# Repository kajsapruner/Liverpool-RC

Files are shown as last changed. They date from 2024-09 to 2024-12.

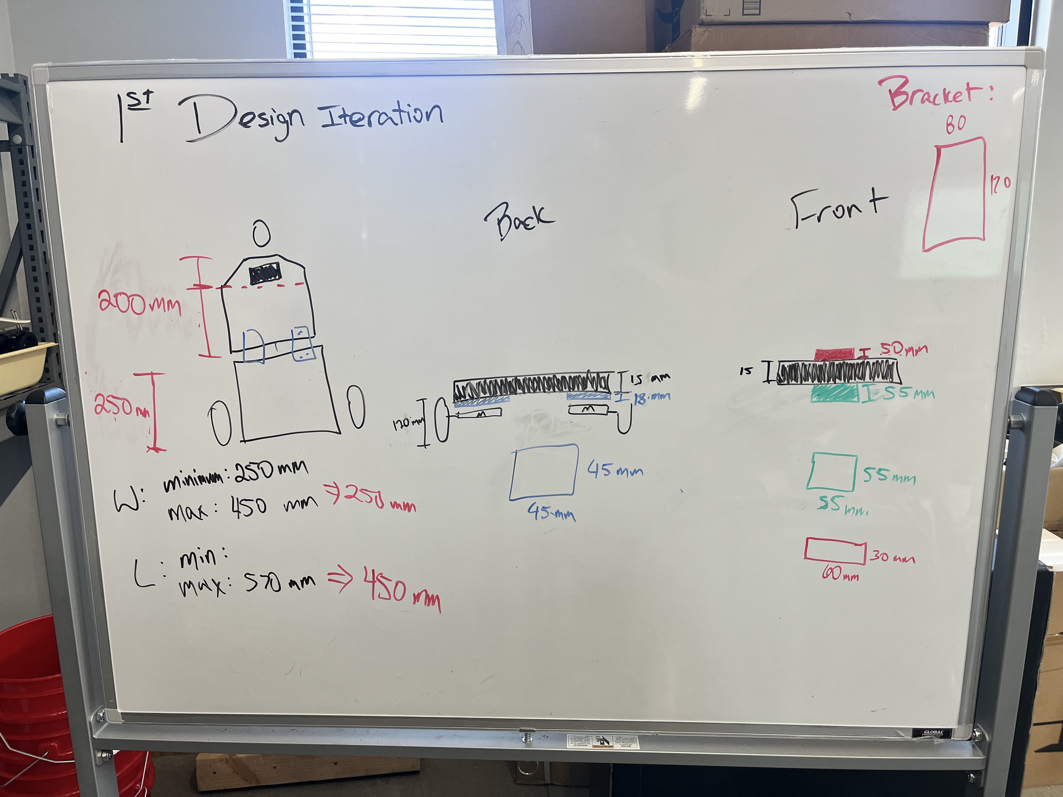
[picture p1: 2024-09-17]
Design Interations/IMG_3937.jpg

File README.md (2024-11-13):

# Liverpool-RC

The Liverpool-RC project is an advanced autonomous driving robot designed to operate using a Raspberry Pi 5 running Raspberry Pi OS. This platform aims to leverage AI and machine learning techniques to enable the robot to navigate and make decisions in real-time, evolving into a fully autonomous self-driving system. Through continuous training and refinement, the robot will learn to recognize and respond to its environment, ultimately developing the capability to drive independently with minimal human intervention. 

## Hardware
Raspberry Pi 5
Raspberry Pi Pico
Voltage Divider
Motor Driver
Switch
Battery
70:1 Motors
Wheels

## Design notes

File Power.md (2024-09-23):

## Power Supplies

### Jetson
To power the Jetson we need a power consumption ranging between 7.5 to 15 W depending on the workload. The input will usually be a 5V-4A (20W) power supply.

### Motors
12V or 24V LiPo (Lithium Polymer Batteries) with high mAh capacity to ensure longer operational time. 

A good idea will be to seperate the Jetson and other electronic components (Like Raspberry Pi Pico) from the motors. We do not want voltage drops and electrical noise. Do this with seperate power supply or voltage regulator.

### Conclusion on what we need:
- 4S 14.8V Lipo Battery (5000mAh)
- seperate 5V 4A regulator from LiPo to Supply Jetson.
- Power motors directly from 12 or 24V battery, or through motor controllers that regulate voltage.

## Switches
For safety reasons and convenience we will have switches between power supplies and components. With these switches we can control what parts of the robot that are powered at a specific time.
After research best option will probably be toggle or rocker switches with appropriate current and voltage (12/24V DC for motors)

One switch will control the entire robot, cutting off power to all the components. Another one will independently control the Jetson, one will disconnect the motor system so that we can power the robot but not activate the motors. The last one will power the Raspberry Pi Pico independently (optional but could be convienient for debugging).

### Conclusion on what we need:
- Master Switch: Use a heavy-duty toggle or rocker switch rated for the voltage of your battery (e.g., 12V or 24V) and at least 10A current.
- Jetson Switch: A smaller switch rated for 5V DC and 5A.
- Motor Switch: A high-current-rated switch, such as a 12V 20A rocker switch.
- Raspberry Pi Pico Switch: Similar to the Jetson, you can use a smaller switch rated for 5V DC and 2-5A.

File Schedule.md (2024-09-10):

### Project Timeline: September to December
## Week 1: September 4 - September 10
- Goal: Initial Setup and Component Integration
- Tasks:
  - Set up the development environment on the Jetson Orin Nano.
  - Install ROS 2 Humble on the Jetson.
  - Verify communication between the Jetson Orin Nano and Raspberry Pi Pico via UART.
  - Test basic motor control using Raspberry Pi Pico.
  - Integrate the RPLIDAR with the Jetson and verify data collection using rplidar_ros.
## Week 2: September 11 - September 17
- Goal: Establish Basic Robot Motion and Data Handling
- Tasks:
  - Develop a custom ROS node on the Jetson for motor command transmission to the Raspberry Pi Pico.
  - Implement basic forward, backward, and turning commands using ROS on the Jetson.
  - Start basic data logging from encoders and RPLIDAR.
  - Review and refine the motor control loop on the Raspberry Pi Pico to ensure accurate execution of commands.
## Week 3: September 18 - September 24
- Goal: SLAM and Initial Mapping
- Tasks:
  - Set up and test the slam_toolbox or cartographer_ros for SLAM using the RPLIDAR.
  - Begin generating initial maps of the test environment.\
  - Start basic localization tasks using robot_localization with encoder data.
  - Evaluate the accuracy of the generated maps and localization.
## Week 4: September 25 - October 1
- Goal: Autonomous Navigation Basics
- Tasks:
  - Set up the navigation2 stack and integrate it with the SLAM system.
  - Implement basic waypoint following using navigation2.
  - Test obstacle avoidance using the RPLIDAR data.
  - Fine-tune the communication between ROS nodes for smooth operation.
## Week 5: October 2 - October 8
- Goal: Sensor Fusion and Odometry Improvement
- Tasks:
  - Implement sensor fusion using robot_localization to improve odometry.
  - Integrate any additional sensors (IMU if available) for enhanced localization accuracy.
  - Continue testing and refining navigation in more complex environments.
  - Analyze and improve the performance of the SLAM and navigation algorithms.
## Week 6: October 9 - October 15
- Goal: Advanced Navigation and Path Planning
- Tasks:
  - Implement advanced path planning strategies with navigation2.
  - Begin testing autonomous navigation through more dynamic environments.
  - Start integrating additional features like object detection if using cameras.
  - Document any challenges and start a troubleshooting log.
## Week 7: October 16 - October 22
- Goal: Integration of Object Detection and AI Features (Optional)
- Tasks:
  - Integrate OpenCV and TensorFlow/PyTorch for any AI-based tasks, if applicable.
  - Start working on object detection, lane following, or other vision-based tasks.
  - Continue refining the SLAM and navigation systems.
  - Perform integration testing with all components working together.
## Week 8: October 23 - October 29
- Goal: Simulation and Testing
- Tasks:
  - Set up and test the robot in Gazebo or a similar simulation environment.
  - Run various scenarios to validate autonomous behavior.
  - Start stress-testing the system with more complex navigation tasks.
  - Collect performance data and make necessary adjustments.
## Week 9: October 30 - November 5
- Goal: Field Testing and Real-World Application
- Tasks:
  - Begin real-world field testing in the intended operational environment.
  - Collect data on performance in different conditions and adjust algorithms as needed.
  - Document any observed issues and start the debugging process.
  - Conduct team reviews to ensure all functionalities are working as expected.
## Week 10: November 6 - November 12
- Goal: Debugging and Optimization
- Tasks:
  - Focus on resolving any outstanding bugs or performance issues.
  - Optimize the communication between the Jetson and Raspberry Pi Pico.
  - Ensure smooth operation of the SLAM, navigation, and motor control systems.
  - Start finalizing the documentation for the project.
## Week 11: November 13 - November 19
- Goal: Final Integration and Testing
- Tasks:
  - Perform full system integration tests.
  - Test the robot's autonomy in various real-world scenarios.
  - Prepare a demo showcasing the robot's capabilities.
  - Gather feedback from team members and stakeholders for any last-minute adjustments.
## Week 12: November 20 - November 26
- Goal: Final Adjustments and Polishing
- Tasks:
  - Make any final tweaks and improvements based on feedback.
  - Ensure all documentation is up to date and comprehensive.
  - Prepare the robot for the final demonstration.
  - Conduct a final review meeting to confirm readiness.
## Week 13: November 27 - December 3
- Goal: Final Presentation and Project Submission
- Tasks:
  - Conduct the final demonstration of the autonomous robot.
  - Submit all project documentation, code, and reports.
  - Celebrate the successful completion of the project!

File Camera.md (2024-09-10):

# Packages that are essential for the Logitech camera

## Jetson Multimedia API
Often already preinstalled on most Jetson boards.

## v4l2 (Video for Linux 2)
Since the logitech camera uses a normal USB port we will need v4l2 so that the Jetson can interface this.
- Package: v4l-utils
- Command: sudo apt-get install v4l-utils
- You can use v4l2-ctl to check if the Jetson detects the camera.

## OpenCV
Will allow us to process the camera´s video feed, can capture frames from USB cameras (like Logitech) and has a number of computer 
vision libraries to help with object detection and image filtering for example.
- Commands:
-     sudo apt-get update
-     sudo apt-get install python3-opencv

## GStreamer
Often used on Jetson boards to support the use of hardware-accelerated video encoding/decoding and is compitable
with OpenCV (might not be neccesary but good to have?????)
- Commands:
-     sudo apt-get install gstreamer1.0-tools
-     sudo apt-get install gstreamer1.0-plugins-base gstreamer1.0-plugins-good

## PyTorch or TensorFlow
This is optional. If we are incorporating deep learning-based navigations (object recognition, reinforcement learning) we
will want either of these installed. Jetson has support for both libraries optimized for its GPUs.
- Follow these instructions to download this: https://docs.nvidia.com/deeplearning/frameworks/install-pytorch-jetson-platform/index.html

# Other resources that I found that can be helpful when downloading packages and installing camera:
## NVIDIA Jetson Forum
Good for troubleshooting and tips
https://forums.developer.nvidia.com/

## NVIDIA Developer Documentation
Includes guides on multimedia, computer vision, and deep learning.
https://docs.nvidia.com/

## GitHub
We can look for Jetson and camera-related repositories here, and take help from other similar projects.

## OpenCV Tutorials
Find tutorials here and documentation specific to video input from cameras. Could help in the installation.
https://opencv.org/

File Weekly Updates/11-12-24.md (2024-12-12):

## Ethan Durham
### This Week: 
- Did some troubleshooting on Virgil, by rewiring the motor driver.
- Assisted in enocoder program for track in the CCCS.
- Began brainstorming ideas for future model training development.
### Future Goals:
- Decide on model we want to use to train Virgil.
- Start collecting data to begin model training.
- Begin a new base design with a main goal of locking rear motors into place, so there is no wiggle when driving.

## Reagan Graff
### This Week: 
- Rewired virgil because of motor driver not working
- Run enocoder program for track in the CCCS but ran into errors
- Connect wireless controller to raspberry pi for future use in training
### Future Goals:
- Decide on model we want to use to train Virgil.
- Improve encoder program for accurate distances

## Kajsa Pruner
### This Week:
- Had surgery
### Future Goals:
- Help training Virgil with the specific model, do research on this model and how to train as well
- Keep communicating with Ethan and Regan what other research I can do, or what we need to troubleshoot etc.

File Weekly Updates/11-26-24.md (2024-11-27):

## Kajsa Pruner
### This Week
- Worked on the report. Wrote about the system design for our robot and about the overall system architechture. Also made a table for the connections from the motor driver to the raspberry pi pico to clarify what GPIO pin # goes where.

### Future Goals
- Try to finish up the report sooner or later. I want to work on it during thansgiving so that we can have our draft done in the beginning of next week.
- Just keep checking in with Reagan and Ethan if they need help with something.

## Reagan Graff
### This Week
- Worked on encoder program. Figured out the tile in the lobby is what is making it travel so inconsistantly
- Work on program that will collect data with our robot model. 
- 

### Future Goals
- Work on report
- Continue program to collect data

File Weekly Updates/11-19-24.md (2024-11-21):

## Kajsa Pruner
### This Week
- Started working on the Final Report
- Helped troubleshooting the encoder program as well as when our pi stopped working (we had to reflash our sd card)
- Created the circuit diagram for our report.
### Future Goals
- I want to have a good base on the report until next week so that we feel like we have made good progress on that, and then just need to add potential additional information about progress that we make.
- Helping to troubleshoot and brainstorm with the encoder program so that we can make this navigation work, since it is 50% of our grade.

## Ethan Durham
### This Week:
- Started Design3 for Back Plate
- Sent program from Robotics1 to assist in encoder movement
- Assisted in troubleshooting motor/shaking wheel.
### Future Goals:
- Help Kajsa with sections of Final Report
- Have encoder program fully functioning

## Reagan Graff
### This Week:
- Work on the data collecting program
- Work on encoder program, ran into some problems
- Switched wheels totroubleshoot shaking as moving
### Future Goals:
- Work on Final Report
- Finalize encoder program
- Progress on the data collecting program

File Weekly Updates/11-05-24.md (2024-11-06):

## Reagan Graff
### This week:
- Wrote encoder program for track
- Wrote test program for object detection and avoidance
- Created poster
- Researched AI and how to train it
### Future Goals:
- Continue training AI
- Brainstorm how to incorporate the AI kit

## Ethan Durham
### This Week:
- Drew and measured map for end of semester project.
- Helped with the poster for INBRE conference
- Started third base design
- Assissted in troubleshooting the robot's movement
### Future Goals
- Finish third base design
- Assist in incorporating AI kit and AI model training for future track.

## Kajsa Pruner
### This week:
- Created Poster for the INBRE conference
- Submitted poster to get printed
- Wrote and tested encoder program for track

### Future Goals:
- Try to help as much as I can with research about training AI to detect the buckets.
- Will have surgery thursday and will not be in class for a week.

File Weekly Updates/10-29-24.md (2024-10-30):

## Reagan Graff
### This week:
- I reflashed the pi is the Raspberry Pi OS
- Installed all dependencies for the AI Kit and Camera
- Cloned a demo repository to test AI camera for object detection
- Troubleshoot the motor driver, hand to fix a miss wire mistake
### Future Goals:
- Write encoder program to naviagte Virgil around the track
- Research how to train Virgil AI

## Ethan Durham
### This week:
- I finished moving all the components onto Virgil, which was the Pi and the AI Camera.
- I replaced the VCC and ground wires for the Left Motor.
- I assisted in troubleshooting the robot's movement.
### Future Goals:
- Draw out a map design for the end of year maze.
- Start a third base design
- Learn more about driving the robot with the motor's encoders
- Do some research on model training using the AI camera/AI kit.

## Kajsa Pruner
### This week:
- Started on the Poster
- Helped troubleshooting the motor driver because some wires and coding was structured wrong.

### Future goals:
- Finish the poster
- research how to train the AI for virgil so that he can detect objects better.

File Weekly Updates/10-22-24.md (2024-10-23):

## Kajsa Pruner:
### This Week:
- Created stand to hold robot so we can test motors
- Helped Reagan with software

### Future Goals:
- Start presentation flyer
- Figure out ORB Slam and how to connect with camera

## Reagan Graff:
### This Week:
- Downloaded ORB Slam, but build froze
- Designed 3D print for switch and camera holder
- Work with Ethan to set up the layout

### Future Goals:
- Reflash card for Raspberry Pi
- Continue to work on ORB Slam
- Test motors and get robot to drive

## Ethan Durham:
### This Week:
- I drilled holes into our base for the Pi to be placed in.
- I 3d printed a pi camera mount to place onto our base.
- I 3d printed a new switch case.
- I soldered wires to our new switch and placed it into the switch case. 

### Future Goals:
- Start a third design iteration.
- Place all outside components, pi camera and pi, onto the base
- Make sure everything is connected, so we can have a drivable robot.
- Screw drill holes for second wire splitter

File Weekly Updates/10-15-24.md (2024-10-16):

## Reagan Graff
### This Week:
- Reinstalled correct ubuntu version onto Raspberry Pi (Ubuntu 24.04.01). 
- Installed all ROS2 Jazzy and all appropriate dependicies and packages.
- Wrote program for camera and detecting objects. 
- Adjusted the wheel driver program to work with our size tires.

### Future Goals
- Get the robot moving and able to drive around the classroom
- Once able to travel with encoders, change program to navigage autonomously. 

## Kajsa Pruner
### This week
- Did some research on Visual SLAM (ORB SLAM). The mapping and Localization. Have not been able to do that much, but will continue next week.
- Printed switch case
- Updated battery pack holder and made the walls thicker, printed this

### Future Goals
- Continue to do research about packages and code we need to get all the functions together (camera, motordriver etc). I specifically want to get better at Visual SLAM because I think this will be crucial for us.
- Do more research on visual SLAM, the mapping and localization.
- FYI. I will be traveling the rest of the week to Florida so will not be in Conway much this week. will be taking a webcamera with me to florida so I can deep diver with the camera and ORB SLAM2 in USL on my computer.

## Ethan Durham
### This Week:
- Successfully transferred the components from old Virgil to the new base.
- Assisted Reagan in confirming the robot can drive.
- Looked over the components to confirm nothing was damaged.

### Future Goals:
- Place a Lidar, new emergency switch case, and the Raspberry Pi onto the base2.
- Start brainstorming/writing down ideas for changes for Base2. 
- Start a third base design iteration.

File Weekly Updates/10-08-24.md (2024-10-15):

## Kajsa Pruner
### This Week:
- Drew and printed a Battery Holder for the Battery so we can mount it and the battery doesnt slide around.
- Finished the Budget & Grant Proposal, sent it to Dr. Fred
- Updated the Parts List with additional parts we need.

### Future Goals
- Do research on how we will make camera detect objects with code
- Start writing code for camera 

## Reagan GRaff
### This Week:
- Switched to the raspberry pi 5
- Researched future parts, such as the AI Kit and AI camera
- Downloaded ubuntu, ros Jazzy, and openCV onto the raspberry pi
- Had problems with ORB SLAM

### Future Goals
- Finish downloading all the required packages
- Write program to get the camera working and be able to detect objects
- Incorporate the motor controller program to get robot moving. 

## Ethan Durham
### This Week:
- I assisted Kajsa in the printing of the battery holder.
- I unmounted all of the components from Old Virgil.
- I created a rough draft on where I want the components to go on New Virgil. 
- I measured out holes for the brackets that mount the wheels.
### Future Goals:
- I want to start a new design iteration that includes pre-drilled screw holes and some other changes (that I have not thought of yet).
- I want to have a robot base that is drivable within the next couple of weeks.

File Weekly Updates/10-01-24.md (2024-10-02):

## Reagan Graff
### This Week:
- I have been researching how opencv works.
- Been having trouble opening opencv so started to reinstall opencv.
### Goals:
- I want to be able to get opencv working, so we can continue onto the next step of getting slam figured out. 

## Kajsa Pruner
### This Week:
- I have been traveling with soccer for the past week, so I have not been able to do much
- Created the Power Point for Friday
- Decided that we want a metal bracket for putting together the two base boards.
### Future Goals
- Draw a holder for the battery that will hold the battery in place, 3D print this.

## Ethan Durham
### This Week:
- I have completed a second design iteration for the new base.
- I pushed the rear wheel mounts forward, cut the thickness of the base in half, and I cut a hole through the base to allow a path for wires. 
- I want to have the new base put together so that I can show it off during the presentation.
- Made the decision to scrap the slide idea for combining the bases. Using Kajsa's idea, we have switched back to using brackets to combine the two parts together. 
### Future Goals:
- I want to have design2 completed and in one piece.
- I want to start transferring the components from old Virgil to new Virgil.
- I want to start a third (final?) design iteration with pre-drilled holes for screws and other additional pieces, like the switch case, battery holder, and camera mount.

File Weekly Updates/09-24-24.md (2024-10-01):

>
> - You can delete comments if merge the pull request.
> - Read Jetson Orin Nano's [datasheet](https://developer.nvidia.com/downloads/assets/embedded/secure/jetson/orin_nano/docs/jetson_orin_nano_devkit_carrier_board_specification_sp.pdf). Find out the answer for 1) input voltage, and 2) DC jack's dimension.

## Reagan Graff
### This Week:
- Installed OpenCV and Slam
> What is "Slam"? attach link for any software installed.
- Helped finish new parts list
> Which part?.
### Goals:
- Test encoder program
> Need to be more specific. For example, verify 5 meter forward and backward traverse on both wheels.
- Figure out opencv and how to use it
> This is too general, let's get started with a smaller goal. How about streaming video in ROS using [cv_bridge](https://index.ros.org/p/cv_bridge/)? 
- Adjust 3D model for switch box

## Ethan Durham
### This Week:
- Finished Design1 Print
- Added components to design1
> What components?.
- Helped finish new parts list
> Which part?.
- Took notes for design2
> Briefly summarize them.
### Goals:
- Start design2
> Please briefly introduce the improvements.
- Print design2
- Get more familiar with 3d design and printing
- Get more familiar with Virgil
> Need to be more specific. For example, establish kinematics model.

## Kajsa Pruner
### This Week:
- Finished the Parts List
- Did research on what Battery Pack we need, and what and how many switches we should use. Refer to the [doc](/Power.md).
> Please read the [datasheet](https://developer.nvidia.com/downloads/assets/embedded/secure/jetson/orin_nano/docs/jetson_orin_nano_devkit_carrier_board_specification_sp.pdf). Then update your design and modify your [document](/Power.md). 5V4A may not be a good choice. 
### Goals:
- Do more research on OpenCV and the Slam so we can figure out how to use it for our purpose in this class (be able to navigate autonomiously). I want to specificly understand more about how to work with these programs with the camera.
> This is somehow too general, need a smaller goal. How about stream the video from camera using [opencv-python](https://pypi.org/project/opencv-python/)?

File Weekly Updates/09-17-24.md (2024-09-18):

# Week of September 17th, 2024

## Kajsa Pruner
### This week:
- Created a document with information of packages that we need to download for our camera. Can be found in giuthub.
- Me and Reagan downloaded started to download the packages and set up the camera so it is working with the functions that we need it to have
### Goals:
- Work on figuring out how we connect the camera to the motors so that it can process the information from the camera and act upon this.
- Research how we will power up our robot. What batteries and other power supplies for example.
- Finish Power point presentation for class on friday.

## Reagan Graff
### This week:
- Downloaded packages and set up the camera, see what packages we downloaded by viewing the document that Kajsa made in Github.
### Goals:
- Work on figuring out how we connect the camera to the motors so that it can process the information from the camera and act upon this.

## Ethan Durham
### This Week:
- Completed first design of new base.
- Added a Design Iteration folder on GitHub
- Print Base Design Iteration 1
### Goals:
- Have design1 put together
- Upgrade/Design second iteration of base
- Continue to learn 3d design and printing

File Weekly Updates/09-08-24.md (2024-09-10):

# Week of September 8th, 2024

## Kajsa Pruner
### This week:
- Created a schedule for the semester so that we have a plan of what we need to do every week, and so that we stay on track.
- Created a google drive where we can store documents that do not need to be placed in Github. For example power points for the presentations can be stored here and easily accessed by everyone.
### Goals:
- Research compatible cameras to use and what packages needed to connect to the Jetson. If have in hand, hook up and verify connection.

## Reagan Graff
### This Week:
- Installed ROS2 Humble on the Jetson and worked on connecting the Raspberry Pi Pico to it. Encountered some issues, which I am currently troubleshooting.
### Goals:
- Resolve connection issues between the Raspberry Pi Pico and Jetson.
- Integrate the RPLIDAR with the Jetson and confirm data collection using the rplidar_ros package.

## Ethan Durham
### This Week:
- Found potential components for design, such as a Logitech camera and a set of 4 McNamum wheels
- Measured the dimensions of the components that were currently on Virgil.
### Goals
- Begin creating/testing a new base design for Virgil.
- Continue to learn more 3D design.

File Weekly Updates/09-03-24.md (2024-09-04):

# September 3rd, 2024

## Kajsa Pruner
### This week:
- Created this respitory in Github.
- Discussed schedules and plans.
- Helped to find screws to the new wheels.
- Me and Reagan were downloading VS code to Jetson, and just spent some time learning this software.
### Goals:
- Create a semester schedule
- Get more familiar with the Jetson
- Start thinking about a new design that could suit better for this class. Virgil is very bulky right now.

## Reagan Graff
### This week:
- Researched the Jetson Orin Nano and collaborated with a team member from another group to install Jetpack 6.0 on a new hard drive.
- Installed jtop, which lets us monitor information and stats on the Jetson.
- Spent some time experimenting with the new Jetson to become more familiar with the software.
- Retrieved the wheel driver code from the Pico and modified the main loop to enable the robot to move forward and backward.
### Goals:
- Finalize the Pico program and upload it to the robot.
- Adjust the robot's wheels to ensure they are synchronized and move straight.
- Calibrating the speeds with the new wheels.

## Ethan Durham
### This week:
- Was introduced to Virgil and the Liverpool-RC project.
- Assisted in troubleshooting and attaching the new wheels and tires onto the robot. 
- Beginning to research CAD design.
### Goals:
- Begin to create a new compact design for Virgil for the future competitions.

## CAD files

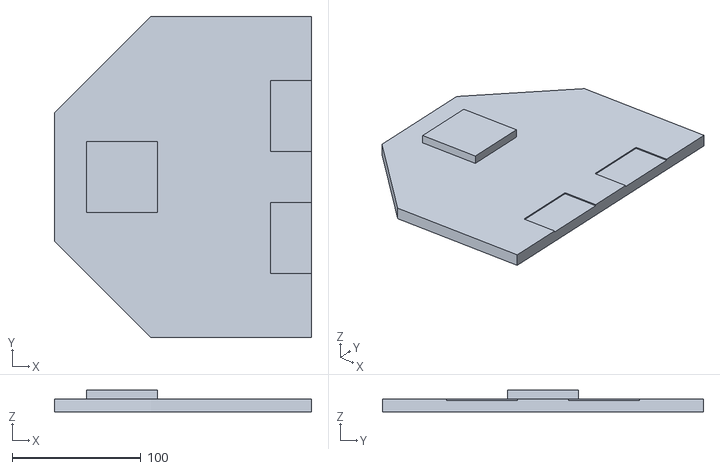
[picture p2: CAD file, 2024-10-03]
Design Interations/Design2Front v2.stl
200.0 x 250.0 x 17.0

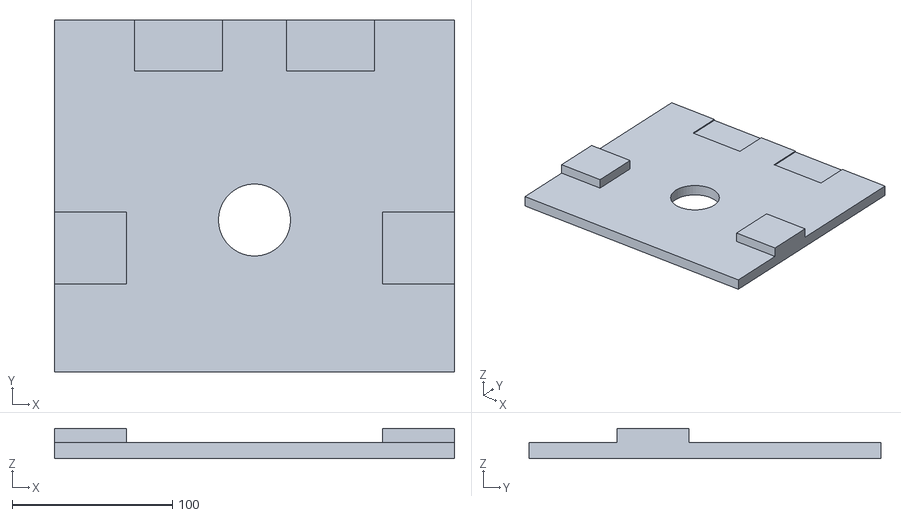
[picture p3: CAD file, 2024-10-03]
Design Interations/Design2Back v5.stl
250.0 x 220.0 x 19.0

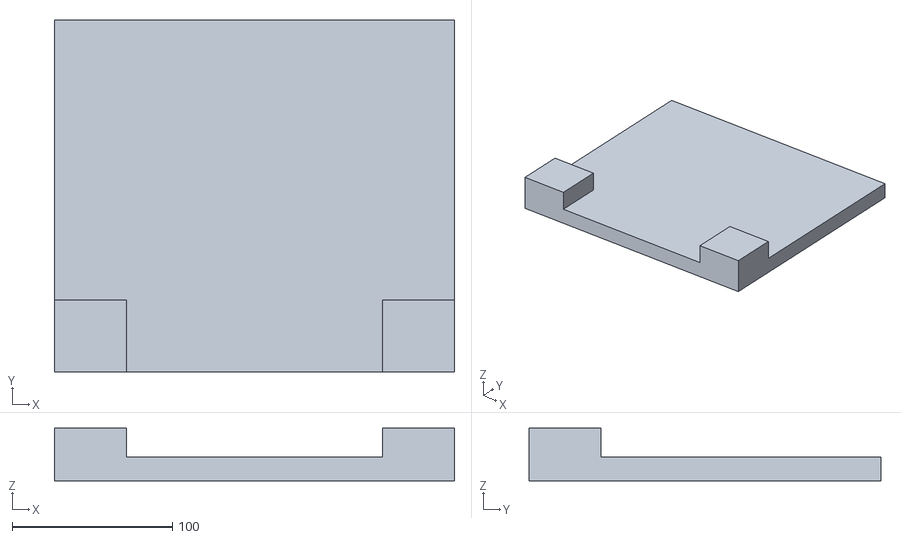
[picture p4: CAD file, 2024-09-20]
Design Interations/Design1Back v2.stl
250.0 x 220.0 x 33.0

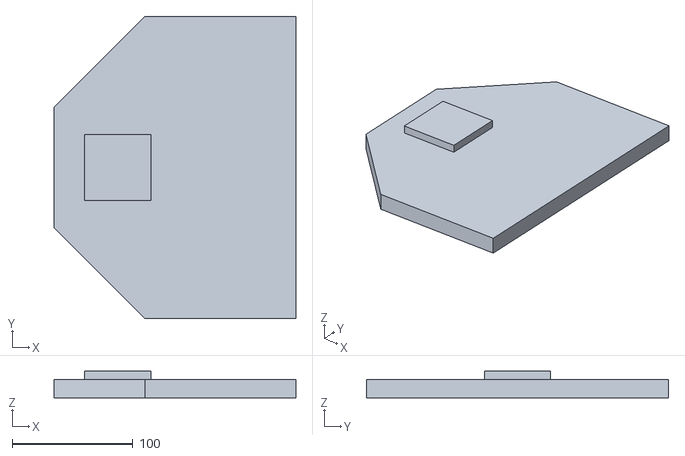
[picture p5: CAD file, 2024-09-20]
Design Interations/Design1Front v1.stl
200.0 x 250.0 x 22.0

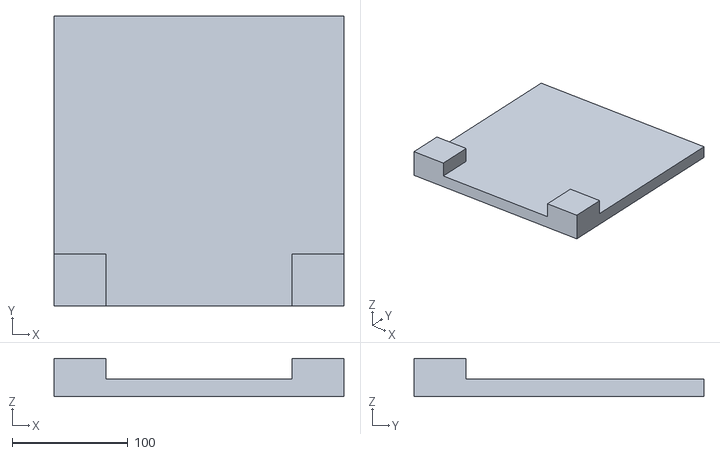
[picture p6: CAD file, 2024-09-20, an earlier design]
Design Interations/Design1Back v1.stl
250.0 x 250.0 x 33.0

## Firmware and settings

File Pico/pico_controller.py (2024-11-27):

import sys
from math import pi
from machine import Pin, PWM, Timer
from time import sleep

class Motor:

    def __init__(self, dir_pin, pwm_pin, enca_pin, encb_pin, slp_pin, ab_order=1, frequency=1000):
        # set pins
        self._dir_pin = Pin(dir_pin, Pin.OUT)
        self._pwm_pin = PWM(Pin(pwm_pin))
        self._enca_pin = Pin(enca_pin, Pin.IN, Pin.PULL_UP)
        self._encb_pin = Pin(encb_pin, Pin.IN, Pin.PULL_UP)
        self._slp_pin = Pin(slp_pin, Pin.OUT)  # Sleep pin
        self._pwm_pin.freq(frequency)
        self._enca_pin.irq(trigger=Pin.IRQ_RISING | Pin.IRQ_FALLING, handler=self._enca_handler)
        self._encb_pin.irq(trigger=Pin.IRQ_RISING | Pin.IRQ_FALLING, handler=self._encb_handler)
        # constants
        self.ab_order = ab_order  # 1: a triggers first; -1: b triggers first
        self.CPR = 64
        self.GEAR_RATIO = 70
        self.encoder_counts = 0
        self.enca_val = self._enca_pin.value()
        self.encb_val = self._encb_pin.value()

        # Stop motor initially
        self.stop()

    def _enca_handler(self, pin):
        # Handle encoder signal change
        self.enca_val = pin.value()
        if self.enca_val == 1:
            if self.encb_val == 0:
                self.encoder_counts -= 1
            else:
                self.encoder_counts += 1
        else:
            if self.encb_val == 1:
                self.encoder_counts -= 1
            else:
                self.encoder_counts += 1

    def _encb_handler(self, pin):
        # Handle encoder signal change
        self.encb_val = pin.value()
        if self.encb_val == 1:
            if self.enca_val == 0:
                self.encoder_counts += 1
            else:
                self.encoder_counts -= 1
        else:
            if self.enca_val == 1:
                self.encoder_counts += 1
            else:
                self.encoder_counts -= 1

    def stop(self):
        # Stop the motor and put to sleep
        self._pwm_pin.duty_u16(0)
        self._slp_pin.value(0)  # Sleep motor

    def forward(self, duty=1.0):
        # Move motor forward
        self._slp_pin.value(1)  # Wake up motor
        self._dir_pin.value(0)
        self._pwm_pin.duty_u16(int(duty*65536))

    def backward(self, duty=1.0):
        # Move motor backward
        self._slp_pin.value(1)  # Wake up motor
        self._dir_pin.value(1)
        self._pwm_pin.duty_u16(int(duty*65536))

    def set_velocity(self, velocity):
        # For direct control, you can set desired velocity here
        self.target_velocity = velocity

    def reset_encoder(self):
        # Reset encoder counts
        self.encoder_counts = 0

class Robot:

    def __init__(self, left_motor_pins, right_motor_pins, frequency=1000):
        assert len(left_motor_pins) == 5
        assert len(right_motor_pins) == 5
        self._left_motor = Motor(
            dir_pin=left_motor_pins[0],
            pwm_pin=left_motor_pins[1],
            enca_pin=left_motor_pins[2],
            encb_pin=left_motor_pins[3],
            slp_pin=left_motor_pins[4],
            ab_order=1,
            frequency=frequency
        )
        self._right_motor = Motor(
            dir_pin=right_motor_pins[0],
            pwm_pin=right_motor_pins[1],
            enca_pin=right_motor_pins[2],
            encb_pin=right_motor_pins[3],
            slp_pin=right_motor_pins[4],
            ab_order=-1,
            frequency=frequency
        )

        self.WHEEL_RADIUS = 0.05
        self.WHEEL_SEPARATION = 0.254

    def forward(self, speed=1.0):
        self._left_motor.forward(duty=speed)
        self._right_motor.forward(duty=speed)

    def backward(self, speed=1.0):
        self._left_motor.backward(duty=speed)
        self._right_motor.backward(duty=speed)

    def stop(self):
        self._left_motor.stop()
        self._right_motor.stop()

    def set_velocity(self, target_lin, target_ang):
        # Set velocity based on desired linear and angular velocity
        left_target_vel = (target_lin - (target_ang * self.WHEEL_SEPARATION) / 2) / self.WHEEL_RADIUS
        right_target_vel = (target_lin + (target_ang * self.WHEEL_SEPARATION) / 2) / self.WHEEL_RADIUS
        self._left_motor.set_velocity(left_target_vel)
        self._right_motor.set_velocity(right_target_vel)

def move_forward_distance(robot, distance, speed=0.5):
    # Calculate the total encoder counts needed to cover the distance
    wheel_circumference = 2 * pi * robot.WHEEL_RADIUS
    wheel_rotations = distance / wheel_circumference
    target_counts = int((wheel_rotations * robot._left_motor.GEAR_RATIO) * (robot._left_motor.CPR))

    # Reset encoder counts
    robot._left_motor.reset_encoder()
    robot._right_motor.reset_encoder()

    # Start moving forward
    robot.forward(speed)

    while robot._left_motor.encoder_counts <= target_counts and robot._right_motor.encoder_counts <= target_counts:
        # Get current encoder counts
        print(f"Left Encoder: {robot._left_motor.encoder_counts}, Right Encoder: {robot._right_motor.encoder_counts}")
        
        if (abs(robot._left_motor.encoder_counts) > abs(robot._right_motor.encoder_counts) + 20):
            robot._left_motor.stop()
            robot._right_motor.forward(speed)
        elif (abs(robot._right_motor.encoder_counts) > abs(robot._left_motor.encoder_counts) + 20):
            robot._right_motor.stop()
            robot._left_motor.forward(speed)
        else:
            robot._right_motor.forward(speed)
            robot._left_motor.forward(speed)
        
        # Check if target counts are reached
        if max(abs(robot._left_motor.encoder_counts), abs(robot._right_motor.encoder_counts)) >= target_counts:
            print(f"Moved {distance} meters.")
            break
        
        sleep(0.01)

    # Stop the robot
    robot.stop()


def turn_90_degrees(robot, clockwise=True, speed=0.5):
    # Calculate the arc distance each wheel needs to travel
    arc_distance = (pi * robot.WHEEL_SEPARATION) / 8  

    # Calculate target encoder counts for the arc distance
    target_counts = (arc_distance / (2 * pi * robot.WHEEL_RADIUS)) * robot._left_motor.CPR * robot._left_motor.GEAR_RATIO

    # Reset encoder counts
    robot._left_motor.reset_encoder()
    robot._right_motor.reset_encoder()

    # Start turning
    if clockwise:
        robot._left_motor.forward(speed)  # Left motor forward
        robot._right_motor.backward(speed)  # Right motor backward
    else:
        robot._left_motor.backward(speed)  # Left motor backward
        robot._right_motor.forward(speed)  # Right motor forward

    while True:
        # Get current encoder counts
        left_counts = abs(robot._left_motor.encoder_counts)
        right_counts = abs(robot._right_motor.encoder_counts)

        # Check if target counts are reached
        if max(left_counts, right_counts) >= target_counts:
            print("90-degree turn complete.")
            break

    # Stop the robot
    robot.stop()


if __name__ == "__main__":
    # Initialize your robot instance
    robot = Robot(left_motor_pins=[3, 2, 14, 15, 4], right_motor_pins=[7, 6, 12, 13, 8])

    # Move forward 2 meters
    print("Moving forward 7 meters...")
    #move_forward_distance(robot, distance=1, speed=0.5)
    #robot.stop()
    #sleep(5)
    # Turn 90 degrees clockwise
    print("Turning 90 degrees clockwise...")
    turn_90_degrees(robot, clockwise=True)

    print("Finished.")

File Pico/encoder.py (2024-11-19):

from machine import Pin, PWM
from time import sleep

class WheelDriver:
    def __init__(self, enca_pin_id, encb_pin_id, dir_pin, pwm_pin, slp_pin, wheel_radius, encoder_resolution):
        self.DIR_PIN = Pin(dir_pin, Pin.OUT)
        self.PWM_PIN = PWM(Pin(pwm_pin))
        self.PWM_PIN.freq(1000)
        self.SLP_PIN = Pin(slp_pin, Pin.OUT)
        self.SLP_PIN.value(1)  # Wake up the motor driver

        self.wheel_radius = wheel_radius  # in meters
        self.encoder_resolution = encoder_resolution  # counts per revolution
        
        # Initialize encoder pins
        self.enca = Pin(enca_pin_id, Pin.IN)
        self.encb = Pin(encb_pin_id, Pin.IN)
        self.encoder_count = 0
        
        # Setup encoder reading (simplified for this example)
        self.enca.irq(trigger=Pin.IRQ_RISING, handler=self.update_encoder)

    def update_encoder(self, pin):
        # Simple encoder count update
        if self.encb.value() == 0:
            self.encoder_count += 1
        else:
            self.encoder_count -= 1
    
    def forward(self, speed=0.5):
        assert 0 <= speed <= 1
        self.DIR_PIN.value(1)  # Set direction to forward
        self.PWM_PIN.duty_u16(int(65535 * speed))  # Set speed

    def backward(self, speed=0.5):
        assert 0 <= speed <= 1
        self.DIR_PIN.value(0)  # Set direction to backward
        self.PWM_PIN.duty_u16(int(65535 * speed))  # Set speed

    def stop(self):
        self.PWM_PIN.duty_u16(0)  # Stop the motor

    def calculate_encoder_counts(self, distance):
        # Calculate the circumference of the wheel
        wheel_circumference = 2 * 3.14159 * self.wheel_radius  # in meters
        
        # Calculate the number of wheel rotations needed to cover the distance
        rotations_needed = distance / wheel_circumference
        
        # Calculate the number of encoder counts needed
        encoder_counts_needed = int(rotations_needed * self.encoder_resolution)
        
        return encoder_counts_needed

class Virgil:
    def __init__(self, left_wheel_driver, right_wheel_driver):
        self.left_wheel = left_wheel_driver
        self.right_wheel = right_wheel_driver

    def forward(self, distance, speed=0.5):
        # Move both wheels forward
        target_counts = self.left_wheel.calculate_encoder_counts(distance)  # Calculate target counts for both wheels
        self.left_wheel.encoder_count = 0  # Reset encoder counts for both wheels
        self.right_wheel.encoder_count = 0  # Reset encoder counts for both wheels

        self.left_wheel.forward(speed)  # Start moving both wheels forward
        self.right_wheel.forward(speed)

        # Continue until both wheels have moved the target distance
        while abs(self.left_wheel.encoder_count) < target_counts or abs(self.right_wheel.encoder_count) < target_counts:
            # Compare the encoder counts and adjust speed to keep the robot moving straight
            left_count = self.left_wheel.encoder_count
            right_count = self.right_wheel.encoder_count

            # If the left wheel is ahead, reduce its speed
            if left_count > right_count:
                self.right_wheel.PWM_PIN.duty_u16(int(65535 * speed))
                self.left_wheel.PWM_PIN.duty_u16(int(65535 * (speed * 0.95)))  # Slow down the left wheel
            # If the right wheel is ahead, reduce its speed
            elif right_count > left_count:
                self.left_wheel.PWM_PIN.duty_u16(int(65535 * speed))
                self.right_wheel.PWM_PIN.duty_u16(int(65535 * (speed * 0.95)))  # Slow down the right wheel

            sleep(0.01)  # Short delay to avoid hogging the CPU

        # Stop both wheels after reaching the target distance
        self.left_wheel.stop()
        self.right_wheel.stop()
        
    def right(self, distance, speed=0.5):
        # Turn right by moving the left wheel forward and the right wheel backward
        target_counts = self.left_wheel.calculate_encoder_counts(distance)
        self.left_wheel.encoder_count = 0
        self.right_wheel.encoder_count = 0

        self.left_wheel.forward(speed)
        self.right_wheel.backward(speed)

        while abs(self.left_wheel.encoder_count) < target_counts:
            # Compare the encoder counts and adjust speed to keep the robot turning consistently
            left_count = self.left_wheel.encoder_count
            right_count = self.right_wheel.encoder_count

            if left_count > right_count:
                self.right_wheel.PWM_PIN.duty_u16(int(65535 * speed))
                self.left_wheel.PWM_PIN.duty_u16(int(65535 * (speed * 0.95)))  # Slow down the left wheel
            elif right_count > left_count:
                self.left_wheel.PWM_PIN.duty_u16(int(65535 * speed))
                self.right_wheel.PWM_PIN.duty_u16(int(65535 * (speed * 0.95)))  # Slow down the right wheel

            sleep(0.01)

        self.left_wheel.stop()
        self.right_wheel.stop()

    def left(self, distance, speed=0.5):
        # Turn left by moving the right wheel forward and the left wheel backward
        target_counts = self.left_wheel.calculate_encoder_counts(distance)
        self.left_wheel.encoder_count = 0
        self.right_wheel.encoder_count = 0

        self.left_wheel.backward(speed)
        self.right_wheel.forward(speed)

        while abs(self.right_wheel.encoder_count) < target_counts:
            # Compare the encoder counts and adjust speed to keep the robot turning consistently
            left_count = self.left_wheel.encoder_count
            right_count = self.right_wheel.encoder_count

            if left_count > right_count:
                self.right_wheel.PWM_PIN.duty_u16(int(65535 * speed))
                self.left_wheel.PWM_PIN.duty_u16(int(65535 * (speed * 0.95)))  # Slow down the left wheel
            elif right_count > left_count:
                self.left_wheel.PWM_PIN.duty_u16(int(65535 * speed))
                self.right_wheel.PWM_PIN.duty_u16(int(65535 * (speed * 0.95)))  # Slow down the right wheel

            sleep(0.01)

        self.left_wheel.stop()
        self.right_wheel.stop()
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

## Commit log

2024-09-03 pico folder
2024-09-04 encoder driver program
2024-09-20 Added Design1 back and front print files
    [Design1Back v1.stl, Design1Front v1.stl]
2024-09-20 Pushed wrong front design
    [Design1Front v2.stl]
2024-09-20 Delete Design Interations/Design1Front v2.stl
    I'm just an idiot and pushed the same thing twice
    [Design1Front v2.stl]
2024-09-20 Added second version of back design
    [Design1Back v2.stl]
2024-10-03 Added Design2 files
    [Design2Back v5.stl, Design2Front v2.stl]
